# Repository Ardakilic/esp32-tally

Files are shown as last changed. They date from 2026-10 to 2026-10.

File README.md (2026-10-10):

# ESP32 Tally Counter

A pocket tally counter: two buttons, a 0.91" OLED, an ESP32-C3 Super Mini and a
1000 mAh LiPo in a 58 × 58 × 22 mm 3D-printed case. Right button counts up, left
counts down, hold both for a second to reset. The count survives power-off, the
device deep-sleeps after 60 s and wakes on any button, and a slide switch cuts
power completely. Two firmwares share the same hardware: a **plain** one with no
radio, and an **ESPHome** one that exposes the count to Home Assistant. Everything
— the case STLs, the README images, both firmware binaries — is generated from
source through Docker + `make`; nothing is installed on the host.

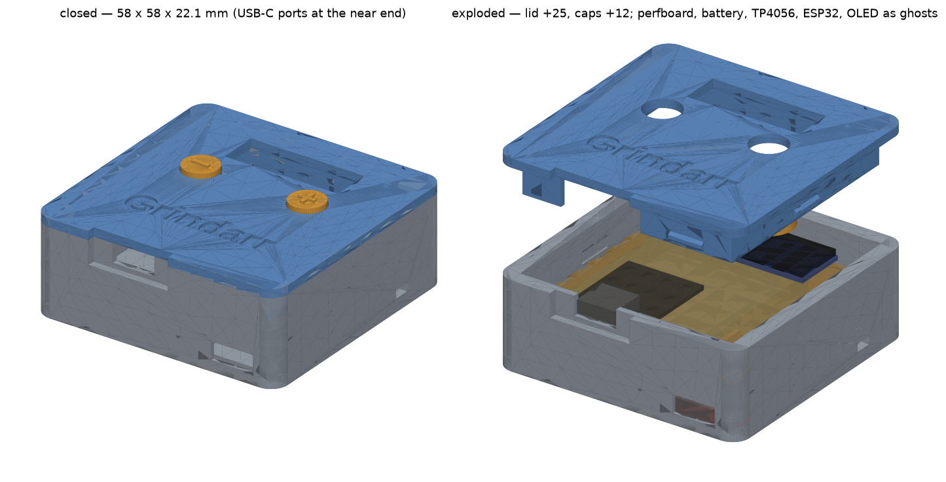
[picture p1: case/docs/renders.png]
Tally counter case — closed and exploded

*Closed (58.0 × 57.6 × 22.1 mm, both USB-C ports at the near end, "Grindarr"
engraved in the lid) and exploded, with perfboard, battery, TP4056, ESP32 and OLED
as ghosts.*

**Interactive preview:** [ardakilic.github.io/esp32-tally](https://ardakilic.github.io/esp32-tally/)
— or open [`case/preview.html`](case/preview.html) locally (self-contained, works offline).

## Features

- **UP** (right, "+") and **DOWN** (left, "−") buttons, range 0…99999, DOWN stops
  at 0; a click counts on **release**, debounced 20 ms.
- Hold **both ≥ 1 s → reset to 0**; the two releases that follow do not count.
- Count **saved to flash on every click** (NVS on the plain build, ESPHome `globals`
  with `restore_value` on the other): a power cut never loses a count. NVS is
  log-structured, so that is tens of millions of clicks before wear matters.
- **60 s idle → OLED off + deep sleep**; either button wakes it (that press is not
  counted). Slide switch = hard power off.
- **Charging over USB-C** through a TP4056 module with cell protection; the ESP32's
  own USB-C is for flashing only and sits behind the lid (see [Power notes](#power-notes)).
- ESPHome variant adds Home Assistant entities: number **Tally Count** (settable),
  button **Reset Tally**, switch **Keep Awake** (blocks the idle sleep so OTA can run).
- Case: snap-fit lid (four detents, bite tunable with [`--snap-bite`](#fit-tuning),
  `0` = plain friction fit), no screws, no supports, 4 parts, 26 cm³ of plastic; the
  lid is engraved "Grindarr" by default — any text or none ([Engraving](#engraving)).

## Bill of materials

| Part | Notes |
|---|---|
| ESP32-C3 Super Mini | the 18 × 22.5 mm board with two 8-pin rows; on male pin headers |
| 0.91" SSD1306 OLED, 128 × 32, I2C | 4-pin header (GND VCC SCL SDA on most — verify yours), address 0x3C |
| 2 × 6 × 6 mm tact switches | any height 4.3–6 mm; default 5.0, see [`--tact-height`](#fit-tuning) |
| TP4056 USB-C charger module | the common 17 × 28 mm board **with** DW01 protection (the variant with OUT+/OUT− pads); 1 A default |
| SS12D00 slide switch | 3-pin, 1P2T, 8.8 × 3.9 × 3.5 mm body, 2 mm travel |
| 1S LiPo pouch, 503450 | 34 × 50 × 5 mm, 1000 mAh, with PCM and JST-PH lead; other sizes via [`--battery`](#fit-tuning) (T ≤ 7 mm) |
| [Özdisan 5 × 5 cm perfboard](https://www.ozdisan.com/p/prototipleme-devreleri-621/ozd-arduino-delkl-pertnaks-5x5-643014) | single-sided, 50 × 50 mm, **18 × 19 holes** at 2.54 mm, used **whole** — no cutting |
| Male pin headers | 2 × 8 for the Super Mini |
| Hook-up wire | thin silicone wire for the dozen connections below |
| 4 printed parts | base, lid, cap "+", cap "−" ([Case](#case)) |
| Hot glue | one dab to hold the slide switch — never on the cell or the perfboard |
| Kapton tape (or 0.3–0.5 mm PET / fish paper) + double-sided foam tape | insulate the perfboard's solder side; fix cell and TP4056 to the floor ([Assembly](#assembly)) |
| Optional: 3 mm foam pad | under the OLED's free end so it can't rock on its header |

## Wiring

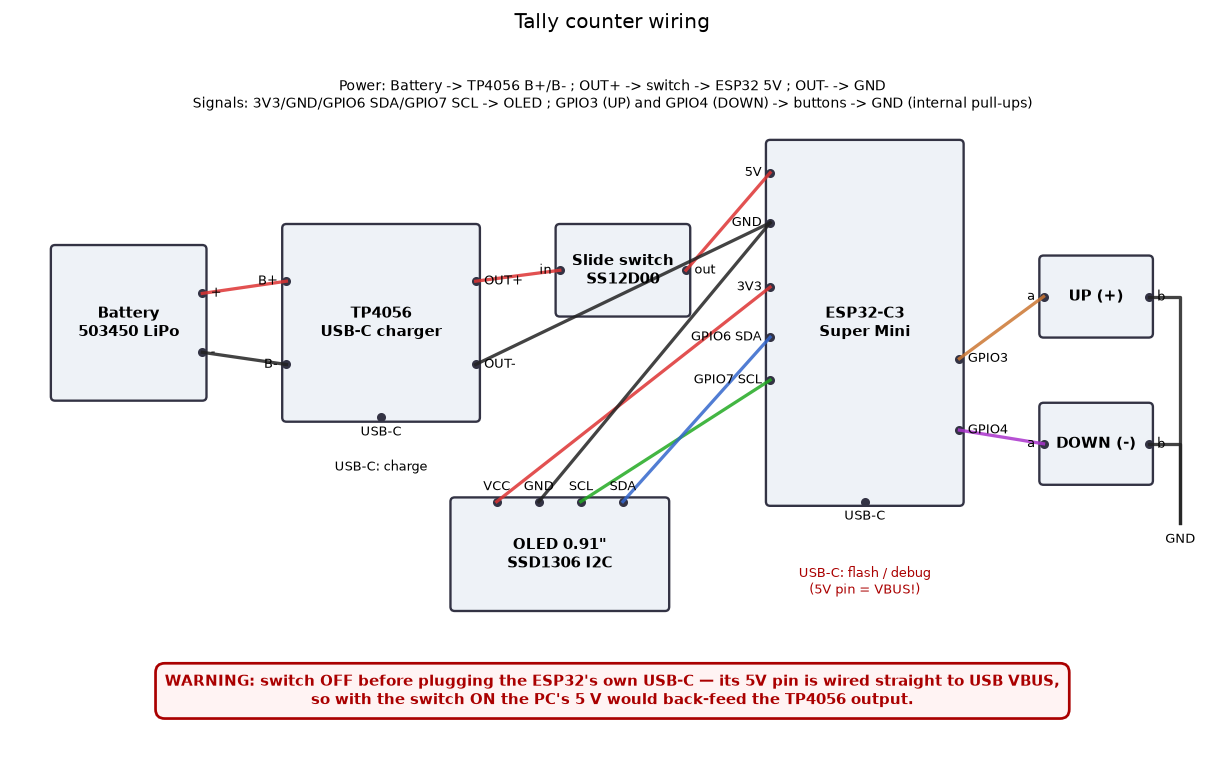
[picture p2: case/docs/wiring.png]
Wiring block schematic


| From | To | Notes |
|---|---|---|
| Battery + / − | TP4056 `B+` / `B−` | solder the JST-PH lead directly to the pads |
| TP4056 `OUT+` | slide switch common | the switched node is on the **high** side |
| slide switch throw (one of the two) | ESP32 `5V` | `5V` = USB VBUS net, see Power notes |
| TP4056 `OUT−` | ESP32 `GND` | OUT− is the protection-switched ground — star all grounds here |
| ESP32 `3V3` / `GND` | OLED `VCC` / `GND` | |
| ESP32 `GPIO6` | OLED `SDA` | I2C 0x3C |
| ESP32 `GPIO7` | OLED `SCL` | |
| UP button, pin 1 / pin 2 | ESP32 `GPIO3` / `GND` | internal pull-up, active low |
| DOWN button, pin 1 / pin 2 | ESP32 `GPIO4` / `GND` | internal pull-up, active low |

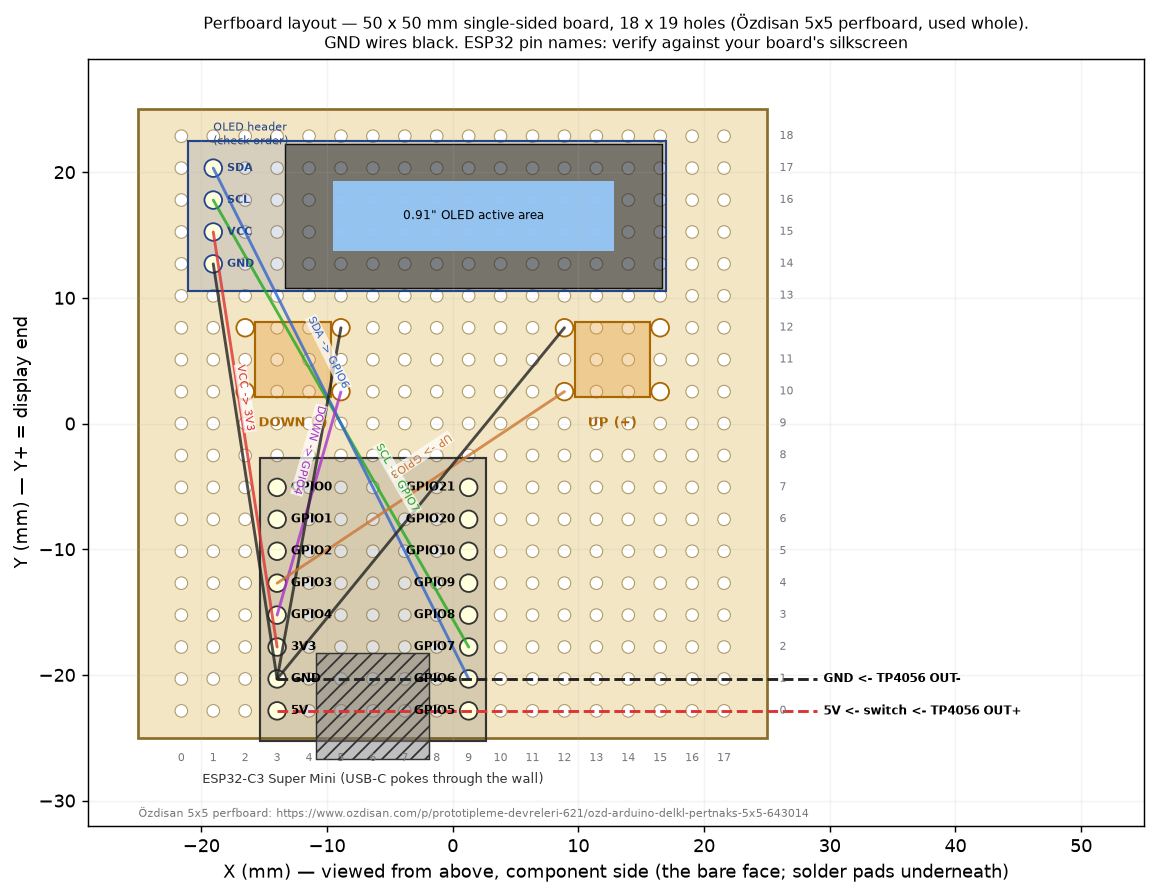
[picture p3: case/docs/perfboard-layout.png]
Perfboard layout


The perfboard is an [Özdisan 5 × 5 cm single-sided board](https://www.ozdisan.com/p/prototipleme-devreleri-621/ozd-arduino-delkl-pertnaks-5x5-643014)
used **whole**: 50 × 50 mm, 18 × 19 holes at 2.54 mm, no cutting. It drops onto the
ledge inside the case with the 19-hole direction along the length (Y, towards the
display end) and the 18-hole direction across (X). The hole grid is centred on the
board — outer row centres 2.14 mm from the Y edges, outer column centres 3.41 mm
from the X edges. Single-sided means the square solder pads are on one face only:
components sit on the bare face, pads underneath. The drawing above is the
**component-side view**, so hole positions appear mirrored once you flip the board
to solder. Column 0 / row 0 is the bottom-left corner when the display end is up.
The Super Mini's two pin rows go into **columns 3 and 9, rows 0…7**, USB-C at the
bottom edge — column 3 carries 5V, GND, 3V3, GPIO4, GPIO3, GPIO2, GPIO1, GPIO0
from the USB end up and column 9 carries GPIO5, GPIO6, GPIO7, GPIO8, GPIO9,
GPIO10, GPIO20, GPIO21 (verified against the mischianti photo pinout and on a
real board, 2026-10-10); because row 0 sits only 2.14 mm from the board edge the receptacle
face ends up just 1.72 mm past the perfboard, so the case wall is relieved from
the outside to a 1.4 mm thin wall there and the port sits 0.2 mm behind it.
The two tact switches are centred at **X ±12.7 mm on row 11** — their four legs land
in columns 2 & 5 (DOWN) and 12 & 15 (UP), rows 10 & 12. The OLED's 4-pin header
goes into **column 1, rows 14…17**, with the module extending to the right across
the top of the board. Pin names in the drawing match the real board — still
**verify against your board** before soldering, Super Mini pinout images disagree
on mirroring; OLED header order varies (GND VCC SCL SDA on most modules).

> **Rework note.** If you built the board from a drawing dated before 2026-10-10,
> the two ESP32 columns were mirrored: move every wire that lands on the module
> to the other column at the same row (5V, GND, 3V3, SDA, SCL, UP, DOWN) — the
> firmware is unchanged.

### Power notes

Verified from the Super Mini schematic (links in
[Verified part geometry](#verified-part-geometry)):

- **The `5V` header pin is the USB VBUS net** — it sits *before* the BAT60J Schottky
  diode and the ME6211 3.3 V LDO. **Flip the slide switch OFF (or unplug the
  battery) before plugging a cable into the ESP32's own USB-C**, otherwise the PC's
  5 V back-feeds the TP4056 output and the battery. This is why the case hides the
  ESP32 port: you open the lid to flash.
- Battery path: V<sub>bat</sub> → BAT60J (≈0.2–0.3 V drop) → ME6211 → 3V3. Regulation
  holds down to ≈3.6–3.7 V; below ≈3.4 V the 3V3 rail sags — the plain build keeps
  running, the Wi-Fi build may brown out. The TP4056's DW01 cuts the cell at 2.4 V
  regardless, so nothing is damaged, the display just gets flaky near empty.
- The Super Mini's **red power LED** draws ≈1–3 mA even in deep sleep when fed
  through `5V`. Flip the switch when storing the counter, or desolder that LED
  for µA-level sleep.
- **Charge current** is the TP4056 default **1 A** (R<sub>PROG</sub> 1.2 kΩ): fine
  for cells ≥ 1000 mAh. For smaller cells swap R<sub>PROG</sub> (2 kΩ ≈ 580 mA).
- **Charge with the switch OFF** so the TP4056's full-charge indication isn't
  confused by the load.
- **Charging/USB test with the switch ON** back-feeds the cell through `OUT+` =
  `B+` with no current control; macOS may disable the port ("USB Accessories
  Disabled"). **Switch OFF first, always.**
- `OUT−` is the protection-switched node (DW01 switches the low side): star the
  grounds at `OUT−`, never at `B−`.

## Firmware

Both firmwares implement the same behaviour and pinout; pick one. Build outputs
are gitignored — `make` regenerates them from pinned Docker images.

### Plain (no network)

[`firmware/plain/`](firmware/plain/) — PlatformIO + Arduino core 3.3.12
(pioarduino platform 55.03.312-1), board `nologo_esp32c3_super_mini`,
`flash_mode = dio`, one library: U8g2 2.36.18.

| File | Role |
|---|---|
| [`platformio.ini`](firmware/plain/platformio.ini) | platform / board / U8g2 pins |
| [`src/tally_logic.h`](firmware/plain/src/tally_logic.h) | the button/count state machine — pure C++, no Arduino |
| [`src/main.cpp`](firmware/plain/src/main.cpp) | pins, OLED, NVS (`Preferences`, written on every click), deep sleep, boot blink + serial banner |
| [`test/tally_logic_test.cpp`](firmware/plain/test/tally_logic_test.cpp) | assert-based self-test of the state machine, runs on the host in `gcc:14` |
| [`Dockerfile`](firmware/plain/Dockerfile) | `python:3.12-slim` + platformio 6.2.0 + git, `PLATFORMIO_CORE_DIR=/pio` |

```bash
make plain-test   # host self-test: prints OK
make plain        # -> firmware/plain/build/tally-plain.factory.bin
```

Result: RAM 4.6 % (15.2 KB), Flash 25.2 % (330 KB), merged image 403 KiB. The
`.factory.bin` is the complete flash image (bootloader @0x0, partitions @0x8000,
boot_app0 @0xe000, app @0x10000) — flash it at offset 0. No OTA: reflashing means
opening the lid.

Liveness check: the Super Mini's **blue LED** (GPIO8) blinks ≈0.3 s on every boot
and wake, so a blink with a dark OLED means the MCU runs and the display (or its
wiring) is the problem. The USB serial port (115200) prints
`boot reset=<esp_reset_reason> wake=<esp_sleep_wakeup_cause>` and the restored
count at boot, then `count=N` per click. A button stuck low (solder bridge, jammed
cap) cannot hold the chip awake: `setup()` seeds the button state instead of
waiting for a release (so the wake press still doesn't count), and a pin that is
low at sleep time is left out of the wake mask.

### ESPHome (Home Assistant)

[`firmware/esphome/tally.yaml`](firmware/esphome/tally.yaml) — ESPHome 2026.9.1,
`esp-idf` framework, board `nologo_esp32c3_super_mini`. Substitution
`idle_sleep: 60s`. Entities in HA: number **Tally Count** (0…99999, box mode,
settable), button **Reset Tally**, switch **Keep Awake**.

1. Secrets: `cp firmware/esphome/secrets.yaml.example firmware/esphome/secrets.yaml`
   and fill in `wifi_ssid`, `wifi_password`, `api_key` (`openssl rand -base64 32`;
   used for both the HA API and OTA) and `ap_password` (fallback hotspot, ≥ 8 chars).
   `secrets.yaml` is gitignored; `make esphome` refuses to run without it.
2. Build (the container needs internet the first time: the Roboto font comes from
   Google Fonts at compile time, the IDF toolchain lands in the cache volume):

```bash
make esphome-config   # validate tally.yaml
make esphome          # -> firmware/esphome/.esphome/build/tally/build/firmware.factory.bin (983 KB)
                      #    and firmware.ota.bin next to it
make esphome-ota      # compile + OTA to DEVICE (default tally.local) after the first USB flash
```

Result: Flash 51 %, RAM 33 %. The device **still sleeps after 60 s** with Wi-Fi: HA
shows it unavailable in between, it reconnects on every wake and pushes the count.
Before an OTA, press a button to wake it and turn on **Keep Awake** within 60 s;
turning it off re-arms the idle timer.

### Flashing

Docker Desktop on macOS cannot pass USB through, so flash from the browser:

1. **Slide switch OFF** (or battery disconnected) — see [Power notes](#power-notes).
2. Open <https://web.esphome.io> in Chrome or Edge → **Connect** → pick the Super
   Mini's serial port → **Install** → choose the `.factory.bin`
   (`firmware/plain/build/tally-plain.factory.bin` or
   `firmware/esphome/.esphome/build/tally/build/firmware.factory.bin`).
3. If no port shows up, hold **BOOT** (GPIO9) while plugging the cable in, then retry.

Both images are full factory images, so switching between the two firmwares is just
another flash. After the first ESPHome flash, later updates go over the air
(`make esphome-ota`).

## Case

[`case/`](case/) — one Python script ([`generate.py`](case/generate.py), shapely +
trimesh + manifold3d, pinned, `python:3.14-slim`) builds four watertight STLs; the
same constants drive the README images and the geometry self-test.

### Parts

| STL | Size (mm) | Volume | Print orientation |
|---|---|---|---|
| [`case/stl/tally-base.stl`](case/stl/tally-base.stl) | 58.0 × 57.6 × 20.1 | 17.2 cm³ | upright, as exported |
| [`case/stl/tally-lid.stl`](case/stl/tally-lid.stl) | 58.0 × 57.6 × 9.5 | 7.4 cm³ | as exported (top face down) |
| [`case/stl/tally-cap-plus.stl`](case/stl/tally-cap-plus.stl) | 11 × 11 × 6 | 0.4 cm³ | on its flange, as exported |
| [`case/stl/tally-cap-minus.stl`](case/stl/tally-cap-minus.stl) | 11 × 11 × 6 | 0.4 cm³ | on its flange, as exported |

Closed: **58.0 × 57.6 × 22.1 mm** (frame opening 50.6 × 50.6, cavity 54.0 × 53.6).
Shell 2.0 mm walls / floor / lid plate, 1.2 mm lid skirt, 4 mm outer corner radius.
Features: snap-fit lid whose skirt slides *inside* the frame (0.28 mm clearance
per side) and clamps the perfboard onto an internal ledge — four 8 mm snap detents
on the skirt's outer face (X− and X+ walls at Y = 0, Y+ wall at X = 0, Y− wall
right of the USB notch at X = +14.2) click into closed 0.5 mm grooves in the
frame's inner face; the crest bites 0.4 mm past the frame, both ramps are 45° so
the lid still pries off, and `--snap-bite 0` gives the plain friction fit; 27 × 9 mm OLED
window; two Ø8.4 mm cap holes; "Grindarr" engraved 0.6 mm into the lid top
([Engraving](#engraving)); an open-top slot in the bottom wall for the ESP32's
USB-C, closed by a notch in the lid skirt (left, flash/debug) — the wall's outer
face is relieved there to a 1.4 mm thin wall, 19 mm wide, and the lid plate is
notched over it so a plug reaches the port; a USB-C window at floor level for the
TP4056 (right, charge); slide-switch slot on the right wall; 10 × 1.5 mm pry notch
at the display end.

### Printing

- 0.2 mm layers, 0.4 mm nozzle. **PETG preferred**: the lid skirt flexes ≈0.7 mm
  riding over the snap bumps. For PLA print a shallower bite,
  `make case GEN_ARGS="--snap-bite 0.3"` (or `--snap-bite 0` for the plain friction
  fit).
- **No supports** in the exported orientations — the overhangs are the ledge's
  underside inside the base, 1.5 mm (ends) to 1.7 mm (sides) wide, and the four
  snap-groove ceilings (0.5 mm deep); both print fine at 0.2 mm layers. The lid's
  snap bumps are 45° ramps and print face-down as before.
- The **thin 1.4 mm wall around the ESP32 port is intentional** (plug relief in the
  bottom wall's outer face, 19 mm wide, from 2 mm above the perfboard up to the
  rim) — don't thicken it in the slicer.
- Base upright; lid as exported (top face on the bed, so the window edge, the
  engraving and the outer face are clean); caps on their flanges.

### Assembly

1. **TP4056**: USB-C first into the lower opening at the bottom end, the PCB end
   sinks 1 mm into its wall pocket; it lies against the right wall, the stop block
   sits behind it.
2. **Battery** into the left bay (lead towards the TP4056; the rib between them
   keeps the pouch off the charger).
3. **Slide switch**: drop it between its two ribs from the inside, handle through
   the slot in the right wall; a dab of hot glue holds it.
4. Solder and route the wires (table above); keep them below the ledge.
5. **Insulate the solder side**: clip every pin tail under the perfboard to
   ≤ 1 mm, then cover the **whole** solder side with Kapton/polyimide tape (two
   layers over the header stubs) or a 0.3–0.5 mm PET / fish-paper sheet cut to
   50 × 50. The ESP32 and OLED header stubs sit directly over the battery bay with
   ≈2 mm of air; a LiPo pouch is 40 µm aluminium foil under 25 µm of nylon, so two
   stubs pressed into it are shorted together (SDA and SCL are 2.54 mm apart), and
   the TP4056's USB shell and `B−`/`OUT−` pads are ground.
6. **Fix the cell and the TP4056 to the case floor** with double-sided foam tape —
   never hot glue against the pouch or the perfboard underside. Hot glue
   (175–200 °C) plus pressure on a pouch is a safety risk, and glue that shrinks or
   is peeled off later cracks single-sided solder joints (the OLED's four first).
7. **Perfboard** onto the ledge, pads down, ESP32 USB-C end towards the bottom
   edge, so the receptacle sits in its wall slot.
8. **Caps** into the lid from below — "+" on the right, "−" on the left (as held,
   display up).
9. **Lid** on: the skirt notch goes over the ESP32 end; press down until it clicks
   on all four sides.

Open it by lifting with a coin in the pry notch at the display end — the detents'
release ramps are 45°, so the lid pries off. Optionally stick a 3 mm foam pad under
the OLED's free end before closing.

### Field notes

First build, 2026-10-10: with the TP4056 and cell hot-glued under the board the
OLED stayed dark until the glue came off — contact through the header stubs and
joint stress, not EMI; hence steps 5–6. Dark-display triage, in order: press
**RST**; the serial port appears (`ls /dev/cu.usbmodem*`) and vanishes after 60 s
(deep sleep); [web.esphome.io](https://web.esphome.io) → **Logs** shows `count=N`
per click; the blue GPIO8 blink on boot = MCU alive; then meter the OLED header
(VCC 3.3 V, SDA/SCL idle at 3.3 V) and reflow. A deep-sleeping ESP32-C3 does
**not** wake when USB is plugged in — only a button or RST does — and with the
slide switch ON a USB plug back-feeds the cell ([Power notes](#power-notes)).

### Fit tuning

Printers and kits vary; the four fit parameters (and the lid engraving) are
command-line flags shared by the generator, the image renderer and the verifier:

| Flag | Default | Controls |
|---|---|---|
| `--clear-friction` | 0.28 mm | lid skirt clearance to the frame per side (filtarr's calibrated value); tune in ±0.04 steps |
| `--snap-bite` | 0.4 mm | how far the four lid snap detents bite past the frame's inner face (PETG); PLA ≈ 0.3; `0` = no detents, the plain friction fit (STLs byte-identical to the pre-snap case) |
| `--tact-height` | 5.0 mm | tact switch height, PCB top to plunger top — 4.3 / 5 / 6 are fine, ≤ 6.0 with the default 7.5 mm lid clearance |
| `--battery` | 34x52x6 | battery pouch envelope W×L×T incl. tabs and swelling; T ≤ 7 |
| `--engraving TEXT` | `Grindarr` | text engraved into the lid top ([Engraving](#engraving)); shortcut `make case ENGRAVING="My Text"` |
| `--omit-engraving` | off | plain lid top, no text; shortcut `make case OMIT_ENGRAVING=1` |

```bash
make case GEN_ARGS="--clear-friction 0.32"                  # lid too tight
make case GEN_ARGS="--snap-bite 0.3"                        # PLA lid; 0 = no detents
make case GEN_ARGS="--tact-height 4.3"                      # shorter switches
make case GEN_ARGS="--battery 30x40x5"                      # smaller cell
make case ENGRAVING="My Text"                               # other lid text
make case OMIT_ENGRAVING=1 GEN_ARGS="--tact-height 4.3"     # plain lid; combinable
make case-verify GEN_ARGS="--clear-friction 0.32 --tact-height 4.3"   # check before printing
```

Every other dimension (walls, PCB_Z 9, LID_CLEAR 7.5, window 27 × 9, switch
position SW_Y 14, snap bump SNAP_LEN 8 / SNAP_CREST 0.8, …) is a named constant
with a why-comment at the top of
[`case/generate.py`](case/generate.py).

### Engraving

The lid top carries **"Grindarr"** by default: Liberation Sans Bold, 6 mm cap
height, recessed 0.6 mm (3 layers), centred at (0, −13) in the free band between
the button caps and the USB-port edge, reading upright with the display at the
top. The lid prints top-face-down, so the recess sits on the bed and comes out
crisp. `--engraving TEXT` / `--omit-engraving` (or the `ENGRAVING=` /
`OMIT_ENGRAVING=1` make shortcuts, which append to `GEN_ARGS`) go to
`generate.py`, `verify.py` and `render_docs.py` alike. Longer text auto-shrinks
below 6 mm to stay inside the band; empty text or a glyph the font has no outline
for is rejected (`p.error`). The generator's summary line — repeated in the
preview's Dimensions panel — reads `Engraving: "Grindarr" (6 mm, 0.6 deep)` or
`Engraving: omitted`. The output is `stl/tally-lid.stl` either way; the committed
lid, renders and preview carry "Grindarr". The font comes from `fonts-liberation`
in the case Docker image.

## Interactive preview

Online at **[ardakilic.github.io/esp32-tally](https://ardakilic.github.io/esp32-tally/)**
(the [Pages workflow](.github/workflows/pages.yml) republishes the whole checkout on
every push to `main`; enable Pages once with Source = GitHub Actions), or locally —
[`case/preview.html`](case/preview.html) is one self-contained file (three.js and the
four STLs embedded, no internet needed), open it in any browser. Lift the lid and caps
with the **Explode** slider, toggle each part, switch on **X-ray lid** or the ghost
electronics (perfboard, battery, TP4056, ESP32, OLED, slide switch), and download
the exact STLs from the **Print these four** list; the Dimensions panel repeats the
tolerance, snap, shell and engraving summary `generate.py` prints, so a tuned build shows
its `GEN_ARGS` (the lid's engraving is in the embedded STL). The landing page ([`index.html`](index.html)) links the preview, the
STLs, the README images and both firmware folders.

## Regenerating everything

```bash
make                  # case + plain + esphome
```

| Target | Does | Output |
|---|---|---|
| `make case` | build image, `generate.py`, `tools/render_docs.py`; `ENGRAVING="…"` / `OMIT_ENGRAVING=1` set the lid text | `case/stl/*.stl`, `case/preview.html`, `index.html`, `case/docs/*.png` |
| `make case-verify` | 105 geometry checks on in-memory builds (70 with `--snap-bite 0`, 101 with `--omit-engraving`), exit 1 on failure | PASS/FAIL table |
| `make vendor` | fetch the latest three.js module build (stdlib-only, bare `python:3.14-slim`) | `case/vendor/three.{module,core}.min.js`, `THREE_VERSION` |
| `make plain` | build image, `pio run`, copy the factory image | `firmware/plain/build/tally-plain.factory.bin` |
| `make plain-test` | state-machine self-test in `gcc:14` | `OK` |
| `make esphome` | `esphome compile` (needs `secrets.yaml`) | `firmware/esphome/.esphome/build/tally/build/firmware.{factory,ota}.bin` |
| `make esphome-config` | `esphome config` | validated YAML |
| `make esphome-ota` | `esphome run --device $(DEVICE)` | flashed device |
| `make image-case` / `make image-plain` | (re)build the two Docker images | — |
| `make clean` | removes `case/stl case/docs case/preview.html index.html firmware/plain/.pio firmware/plain/build firmware/esphome/.esphome` | — |

Pinned images: `python:3.14-slim` + [`case/requirements.txt`](case/requirements.txt)
(the exact wheels the committed STLs were triangulated with) + Debian's
`fonts-liberation` for the lid engraving, `python:3.12-slim` +
platformio 6.2.0, `ghcr.io/esphome/esphome:2026.9.1`, `gcc:14`. Caches live in two
named Docker volumes, never on the host: **`esp32-tally-pio`** (PlatformIO core —
pioarduino platform, Xtensa/RISC-V toolchain, Arduino framework, U8g2) and
**`esp32-tally-esphome-cache`** (ESPHome's PlatformIO/IDF cache). First builds
download a few hundred MB into them; rebuilds take seconds. `make clean` leaves
the volumes alone (`docker volume rm esp32-tally-pio esp32-tally-esphome-cache`
if you want them gone).

`case/stl/`, `case/docs/`, `case/preview.html`, `index.html` and `case/vendor/` are
**committed and never hand-edited**: change `generate.py` (or
`case/preview_template.html`), run `make case` + `make case-verify` (or
`make case ENGRAVING="…"` for another lid text), commit the regenerated files
together with the change; `make vendor` only when you want a newer three.js.
`make case-verify` ([`case/tools/verify.py`](case/tools/verify.py)) rebuilds every
part in memory and checks: watertightness; bounding boxes; skirt = opening − 2 ×
clearance; rays through the OLED window, both cap holes, both USB-C openings and
the switch slot; the 1.4 mm wall and port recess at the ESP32 USB-C; that the
battery, TP4056, ESP32, OLED and switch ghosts do not intersect the shell; the
cap-to-hole play; the engraving's depth and footprint (or a plain top with
`--omit-engraving`); and, per snap site, the crest protrusion, groove depth,
seated Z/along-the-wall margins, remaining frame wall, clearance to the USB
relief and skirt notch, plus that `--snap-bite 0` reproduces the no-snap lid and
base exactly. Pass it the same `GEN_ARGS` as `make case`.

## Verified part geometry

Dimensions the case is built around (all in `generate.py` with their sources):

- **ESP32-C3 Super Mini** — PCB 18 × 22.5 mm, two 8-pin rows 15.24 mm apart
  (6 pitches), first pin centre 2.36 mm from the USB edge, USB-C shell 9 × 3.2 mm
  overhanging the PCB by 1.5 mm, module on 2.54 mm header spacers + 1.0 mm PCB;
  `5V` pin = VBUS before the BAT60J diode and ME6211 LDO —
  [schematic (mischianti.org)](https://mischianti.org/wp-content/uploads/2025/07/esp32-c3-supermini-schematics.pdf).
- **ME6211** LDO (3.3 V variant on the board) — low dropout, hence the ≈3.6–3.7 V
  regulation floor quoted above —
  [family datasheet (LCSC)](https://wmsc.lcsc.com/wmsc/upload/file/pdf/v2/lcsc/2201121200_MICRONE-Nanjing-Micro-One-Elec-ME6211C25M5G_C2835813.pdf).
- **6 × 6 mm tact switch** — Omron B3F family: body 6 × 6, plunger Ø3.5, heights
  4.3 / 5.0 / 6.0 / 7.0 mm, legs 6.5 × 4.5 mm apart → 3 × 2 perfboard pitches
  (columns 2 & 5 / 12 & 15, rows 10 & 12) —
  [B3F datasheet](https://omronfs.omron.com/en_US/ecb/products/pdf/en-b3f.pdf).
- **SS12D00 slide switch** — body 8.8 × 3.9 × 3.5 mm, handle 1.5 mm, travel 2.0 mm
  (slot 4.0 × 2.0 mm incl. 0.5 mm play) —
  [datasheet](https://www.vimex.com/switches/techdocs/SS12D00-tech.pdf).
- **0.91" 128 × 32 OLED** — module PCB 38 × 12 mm, glass 30 × 11.5 mm, active area
  22.4 × 5.6 mm, header pin centres 2.0 mm from the short edge, 6.9 mm tall at the
  IC seal cover — [panel datasheet](https://www.icbanq.com/icdownload/V2_DATA/ICBShop/Board/HP12832-01-TSWG14P091-A-VER1.0.pdf).
- **TP4056 USB-C module** — PCB 17 × 28 × 1.0 mm, USB-C shell 9 × 3.2 mm overhanging
  1.0 mm, R<sub>PROG</sub> 1.2 kΩ → 1 A, DW01 protection switching the low side —
  [module manual](https://shillehtek.com/blogs/shillehtek-product-manuals/tp4056-1a-lipo-battery-charging-board-type-c-with-current-protection-manual).
- **503450 LiPo** — 34 × 50 × 5 mm nominal, modelled as 34 × 52 × 6 (PCM tab +
  1 mm swelling) with 0.5 mm air to every wall.
- **Perfboard** — Özdisan 5 × 5 cm single-sided board, used whole: 50 × 50 mm,
  1.6 mm FR4, 18 × 19 holes at 2.54 mm centred on the board (outer row centres
  2.14 mm from the Y edges, outer column centres 3.41 mm from the X edges), square
  pads on one face —
  [product page (Özdisan)](https://www.ozdisan.com/p/prototipleme-devreleri-621/ozd-arduino-delkl-pertnaks-5x5-643014).

## Not yet verified on hardware

One unit has been printed, assembled on the Özdisan board and flashed with the
plain firmware (2026-10-10, see [Field notes](#field-notes)); the ESPHome build
has not run on hardware yet. The rest is from datasheets, the schematic, the
geometry self-test and a host-side test of the state machine. Still open, in the
order they'd bite:

- **Deep-sleep wake on both buttons** (GPIO3 | GPIO4 mask via
  `esp_deep_sleep_enable_gpio_wakeup`) — compiles on both builds, untested on
  silicon; so is the plain build's GPIO8 blue boot blink.
- The ESPHome **`millis() > 1500` wake-press guard** (the press that woke the chip
  is already ON at boot; its release must not count) — margin chosen by reasoning,
  not measured boot time.
- **Friction fit 0.28 mm** is filtarr's calibrated value on a different, larger
  part; expect to tune `--clear-friction`.
- **Snap detents** — 0.4 mm bite, 8 mm bumps, 45° ramps: click force, pry-off
  force and skirt durability (≈0.7 mm flex per close) are unprinted, in PETG and
  PLA alike; the PLA value `--snap-bite 0.3` is reasoning, not measurement.
  `--snap-bite 0` falls back to the friction-only lid.
- **OLED window offset** `OLED_AA_DX` 3.7 mm (active area vs PCB centre) — measure
  your module; it differs between 0.91" boards.
- **OLED header order** — GND VCC SCL SDA assumed in the drawings.
- **TP4056 variant size** — 17 × 28 mm boards are the norm, some USB-C variants
  are 17 × 26 or have the receptacle further in; the wall pocket is 1 mm deep.
- **Thin 1.4 mm wall at the ESP32 USB-C** — the port face ends 0.2 mm behind it;
  whether every cable's overmold seats, and whether the wall prints cleanly at
  that thickness, is unprinted.
- **Engraving legibility** — 6 mm Liberation Sans Bold, 0.6 mm deep, printed
  face-down on the bed; counters of the small letters are untested with a 0.4 mm
  nozzle.

Found something? Open an issue with the measurement.

## License

Dual-licensed:

- **Code** (firmware, generator, tooling): [MIT](LICENSE)
- **Models & images** (STLs, renders): [CC BY 4.0](LICENSE-MODELS) — use, share,
  sell and remix freely, but credit this project with a link back when you
  redistribute the models.

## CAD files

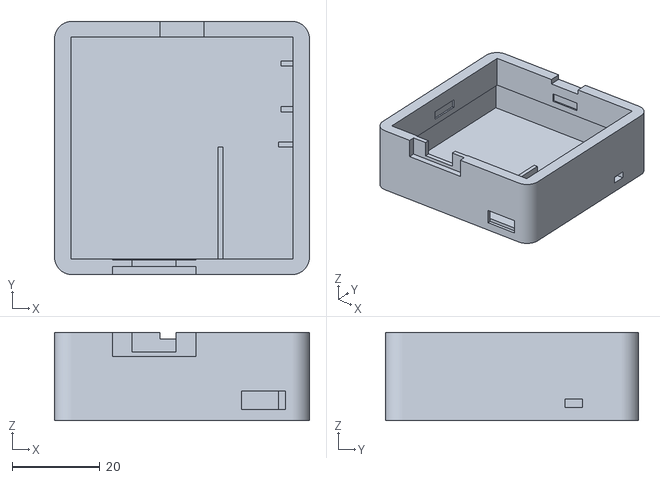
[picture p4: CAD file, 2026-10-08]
case/stl/tally-base.stl
58.0 x 57.6 x 20.1

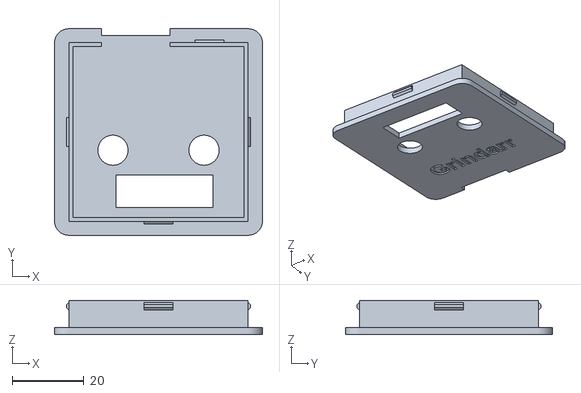
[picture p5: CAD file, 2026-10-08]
case/stl/tally-lid.stl
58.0 x 57.6 x 9.50

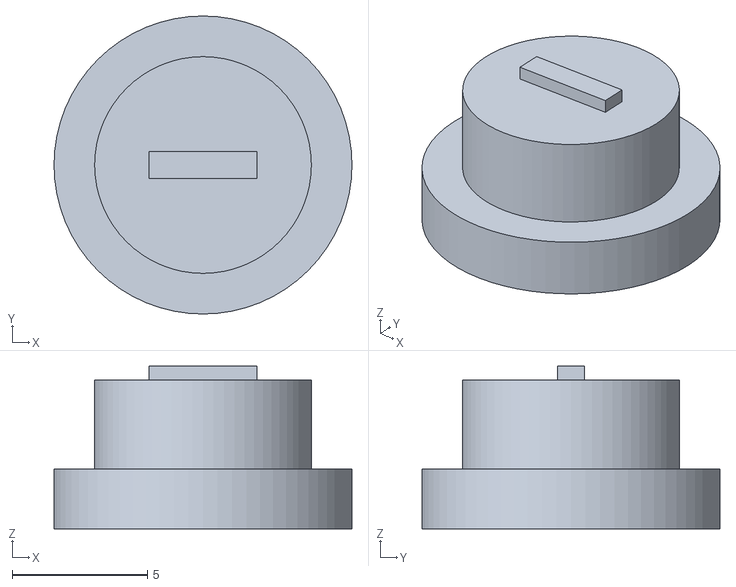
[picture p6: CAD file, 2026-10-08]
case/stl/tally-cap-minus.stl
11.0 x 11.0 x 6.00

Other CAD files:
case/stl/tally-cap-plus.stl

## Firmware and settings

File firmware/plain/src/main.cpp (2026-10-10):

#include <Arduino.h>
#include <Preferences.h>
#include <U8g2lib.h>
#include <esp_sleep.h>
#include "tally_logic.h"

constexpr int BTN_UP = 3, BTN_DOWN = 4;
// Super Mini blue LED: active-LOW with a 10k pull-up, and a strapping pin (must be high at reset).
// Lit only while setup() runs, so a blink on every boot/wake proves the MCU is alive with a dark OLED.
constexpr int LED_PIN = 8;
constexpr uint32_t IDLE_SLEEP_MS = 60000;

U8G2_SSD1306_128X32_UNIVISION_F_HW_I2C u8g2(U8G2_R0, U8X8_PIN_NONE, /*clock=*/7, /*data=*/6);
Preferences prefs;
Tally tally;

static void draw() {
  char buf[8];
  snprintf(buf, sizeof buf, "%ld", (long)tally.count);
  u8g2.clearBuffer();
  u8g2.drawStr((128 - u8g2.getStrWidth(buf)) / 2, 16, buf);
  u8g2.sendBuffer();
}

static void sleepNow() {
  u8g2.setPowerSave(1);
  uint64_t mask = (digitalRead(BTN_UP) ? BIT(BTN_UP) : 0) | (digitalRead(BTN_DOWN) ? BIT(BTN_DOWN) : 0);
  if (mask) esp_deep_sleep_enable_gpio_wakeup(mask, ESP_GPIO_WAKEUP_GPIO_LOW);  // a held/stuck pin would re-wake instantly
  esp_deep_sleep_start();
}

void setup() {
  pinMode(LED_PIN, OUTPUT);
  digitalWrite(LED_PIN, LOW);
  Serial.begin(115200);
  Serial.setTxTimeoutMs(0);  // USB CDC with no host attached must never stall the loop
  Serial.printf("boot reset=%d wake=%d\n", (int)esp_reset_reason(), (int)esp_sleep_get_wakeup_cause());
  pinMode(BTN_UP, INPUT_PULLUP);
  pinMode(BTN_DOWN, INPUT_PULLUP);
  prefs.begin("tally");
  tally.count = prefs.getInt("count", 0);
  Serial.printf("count=%ld (restored)\n", (long)tally.count);
  u8g2.begin();
  u8g2.setFont(u8g2_font_logisoso28_tn);
  u8g2.setFontPosCenter();
  draw();
  digitalWrite(LED_PIN, HIGH);
  pinMode(LED_PIN, INPUT);  // the pull-up keeps it off through deep sleep at zero drive
  // Seed instead of waiting for release: a stuck-LOW button must not block boot and drain the cell.
  tally.up.raw = tally.up.stable = !digitalRead(BTN_UP);
  tally.down.raw = tally.down.stable = !digitalRead(BTN_DOWN);
  tally.combo = tally.up.stable || tally.down.stable;  // the wake press's release must not count
  tally.last_activity_ms = millis();
}

void loop() {
  uint32_t now = millis();
  if (tally.update(!digitalRead(BTN_UP), !digitalRead(BTN_DOWN), now)) {
    draw();
    // Write per click: NVS is log-structured, a 4-byte entry per click into the 20 KB default
    // partition is tens of millions of clicks before wear matters, and a power cut never loses one.
    prefs.putInt("count", tally.count);
    Serial.printf("count=%ld\n", (long)tally.count);
  }
  if (now - tally.last_activity_ms >= IDLE_SLEEP_MS) sleepNow();
  delay(5);
}

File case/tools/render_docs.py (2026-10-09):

#!/usr/bin/env python3
"""Render the README images — software renderer via matplotlib, no GPU/browser:

  docs/renders.png           closed case + exploded view with ghost electronics
  docs/perfboard-layout.png  the 50 x 50 (18 x 19 hole) perfboard from above
                             with every component, pin name and wire
  docs/wiring.png            block schematic (power path + signals)

Usage:  python3 tools/render_docs.py [generate.py flags]
"""

import os
import sys

import numpy as np
import matplotlib

matplotlib.use("Agg")
import matplotlib.pyplot as plt
from matplotlib.patches import Circle, FancyBboxPatch, Rectangle
from mpl_toolkits.mplot3d.art3d import Poly3DCollection
import trimesh

HERE = os.path.dirname(os.path.abspath(__file__))
ROOT = os.path.dirname(HERE)
sys.path.insert(0, ROOT)
import generate as g  # noqa: E402  (has a __main__ guard — importing is free)

DOCS = os.path.join(ROOT, "docs")
GRAY, BLUE, CAP = "#9aa2ad", "#5f8cc4", "#e0a040"
GHOSTS = {  # component box -> translucent colour
    "perfboard": (0.75, 0.55, 0.20, 0.45), "battery": (0.35, 0.65, 0.85, 0.45),
    "tp4056": (0.85, 0.35, 0.35, 0.55), "tp4056-usb": (0.4, 0.4, 0.4, 0.7),
    "esp32": (0.2, 0.2, 0.2, 0.55), "esp32-usb": (0.4, 0.4, 0.4, 0.7),
    "oled": (0.2, 0.3, 0.6, 0.55), "oled-glass": (0.1, 0.1, 0.1, 0.7),
    "switch": (0.9, 0.9, 0.9, 0.9),
}


def show(ax, meshes_cols, elev=28, azim=-55):
    """Flat-shaded render with global painter depth sort (RGBA colours ok)."""
    tris, cols = [], []
    light = np.array([0.35, -0.45, 0.82])
    light /= np.linalg.norm(light)
    for mesh, color in meshes_cols:
        v, f = trimesh.remesh.subdivide_to_size(
            mesh.vertices.astype(np.float64), mesh.faces, max_edge=8.0)
        m = trimesh.Trimesh(v, f)
        shade = 0.5 + 0.5 * np.clip(m.face_normals.astype(np.float64) @ light, 0, 1)
        rgba = np.array(matplotlib.colors.to_rgba(color))
        c = np.tile(rgba, (len(m.faces), 1))
        c[:, :3] = np.clip(shade[:, None] * rgba[None, :3], 0, 1)
        tris.append(m.vertices[m.faces])
        cols.append(c)
    tri, col = np.concatenate(tris), np.concatenate(cols)
    e, a = np.radians(elev), np.radians(azim)
    view = np.array([np.cos(e) * np.cos(a), np.cos(e) * np.sin(a), np.sin(e)])
    order = np.argsort(tri.mean(axis=1) @ view)
    ax.add_collection3d(
        Poly3DCollection(tri[order], facecolors=col[order], edgecolors="none"))
    lo, hi = tri.reshape(-1, 3).min(0), tri.reshape(-1, 3).max(0)
    c, r = (lo + hi) / 2, (hi - lo).max() / 2 * 0.9
    ax.set_xlim(c[0] - r, c[0] + r)
    ax.set_ylim(c[1] - r, c[1] + r)
    ax.set_zlim(c[2] - r, c[2] + r)
    ax.set_box_aspect((1, 1, 1))
    ax.set_proj_type("ortho")
    ax.set_axis_off()
    ax.view_init(elev=elev, azim=azim)


def moved(m, dx=0.0, dy=0.0, dz=0.0):
    c = m.copy()
    c.apply_translation([dx, dy, dz])
    return c


def box_mesh(b):
    return g.bbox(*b)


def render_case(out_path):
    base, lid = g.build_base(), g.build_lid()
    caps = [moved(g.build_cap(s), *xy) for s, xy in zip(("minus", "plus"), g.TACT_XY)]
    closed = [(base, GRAY), (lid, BLUE)] + [(c, CAP) for c in caps]
    ghosts = [(box_mesh(b), GHOSTS[n]) for n, b in g.component_boxes().items() if n in GHOSTS]
    exploded = ([(base, GRAY)] + ghosts + [(moved(c, dz=12.0), CAP) for c in caps]
                + [(moved(lid, dz=25.0), BLUE)])
    fig = plt.figure(figsize=(11, 6), dpi=130)
    ax = fig.add_subplot(1, 2, 1, projection="3d")
    show(ax, closed)
    ax.set_title(f"closed — {g.OUT_W:.0f} x {g.OUT_L:.0f} x {g.Z_TOP + g.LID_T:.1f} mm "
                 "(USB-C ports at the near end)", fontsize=10)
    ax = fig.add_subplot(1, 2, 2, projection="3d")
    show(ax, exploded)
    ax.set_title("exploded — lid +25, caps +12; perfboard, battery, TP4056, "
                 "ESP32, OLED as ghosts", fontsize=10)
    fig.patch.set_facecolor("white")
    plt.tight_layout()
    plt.savefig(out_path, bbox_inches="tight")
    plt.close(fig)
    print("saved", out_path)


# ESP32-C3 Super Mini pin names with the USB at Y-, board viewed from above.
# Left = col 3, right = col 9, rows 0..7 (0 = USB end). Verified against the
# mischianti photo pinout and on a real board 2026-10-10 (an earlier version had
# the two columns mirrored). Still worth a glance at the silkscreen.
ESP_LEFT = ["5V", "GND", "3V3", "GPIO4", "GPIO3", "GPIO2", "GPIO1", "GPIO0"]
ESP_RIGHT = ["GPIO5", "GPIO6", "GPIO7", "GPIO8", "GPIO9", "GPIO10", "GPIO20", "GPIO21"]
OLED_PINS = ["GND", "VCC", "SCL", "SDA"]  # rows 14..17, the usual order — check
OLED_ROWS = range(14, 18)
TACT_ROWS = (10, 12)  # tact pins straddle the body on row 11
ESP_PIN = {**{n: (3, r) for r, n in enumerate(ESP_LEFT)},
           **{n: (9, r) for r, n in enumerate(ESP_RIGHT)}}
# wires: (from hole, to hole, label, colour, label position along the wire 0..1)
WIRES = [
    ((1, 15), ESP_PIN["3V3"], "VCC -> 3V3", "#d33", 0.5),
    ((1, 14), ESP_PIN["GND"], "GND", "#222", 0.5),
    ((1, 16), ESP_PIN["GPIO7"], "SCL -> GPIO7", "#2a2", 0.72),
    ((1, 17), ESP_PIN["GPIO6"], "SDA -> GPIO6", "#36c", 0.45),
    ((5, 10), ESP_PIN["GPIO4"], "DOWN -> GPIO4", "#a3c", 0.5),
    ((5, 12), ESP_PIN["GND"], "GND", "#222", 0.5),
    ((12, 10), ESP_PIN["GPIO3"], "UP -> GPIO3", "#c73", 0.5),
    ((12, 12), ESP_PIN["GND"], "GND", "#222", 0.5),
]
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

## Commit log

2026-10-08 ESP32-C3 tally counter: two firmwares, parametric case, three.js preview
    Handheld click counter on an ESP32-C3 Super Mini with a 128x32 SSD1306 OLED,
    two 6x6 tact buttons (+/-, both held = reset), a TP4056 USB-C charger, a 1S
    LiPo bay and a slide power switch. Count is persisted in flash; the device
    deep-sleeps after 60 s idle and wakes on either button. Everything is
    generated inside Docker (make), nothing is installed on the host.
    - firmware/plain: PlatformIO + Arduino core 3.3 (pioarduino), U8g2, NVS,
    deep sleep; header-only state machine with a gcc self-test
    - firmware/esphome: ESP-IDF build exposing a settable number, a reset
    button and a keep-awake switch to Home Assistant
    - case: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
    [tally-base.stl, tally-cap-minus.stl, tally-cap-plus.stl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]
2026-10-08 Özdisan 50x50 perfboard used whole; optional "Grindarr" lid engraving
    The perfboard is now the specific Özdisan 5x5 cm single-sided board
    (50 x 50 mm, 18 x 19 holes at 2.54 mm) used uncut. The hole grid sits
    further from the board edge than the old cut board, so the Super Mini's
    USB-C port would have been recessed 2 mm; the Y- wall is now relieved
    from the outside to a 1.4 mm thin wall there and the lid plate is notched
    over it, leaving the port 0.2 mm behind the face.
    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
    [tally-base.stl, tally-lid.stl]
2026-10-08 Snap-fit lid: four detents on the skirt, closed grooves in the frame
    The lid was a plain friction fit, which nothing holds when the handheld
    is picked up by the lid or turned over. Four 8 mm detents on the skirt's
    outer face now click into closed 0.5 mm grooves in the frame's inner
    face (X sides at Y 0, Y+ at X 0, Y- right of the USB notch). Symmetric
    45 deg ramps so the lid still pries off at the existing notch.
    - --snap-bite MM (default 0.4; PLA ~0.3; 0 = friction fit, STLs
    byte-identical to before); summary line and preview show the setting
    - verify: new snap scope (crest protrusion, groove depth, seated
    margins, remaining wall, clearance to USB relief and skirt notch,
    bite 0 repro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
    [tally-base.stl, tally-lid.stl]
2026-10-09 Fix mirrored Super Mini header columns in the perfboard drawing
    The layout drawing had the two ESP32-C3 Super Mini pin columns swapped,
    so a board wired from it put the buttons on GPIO8/GPIO9 and the OLED on
    the power pins. With the USB-C at the bottom edge and the board viewed
    from above, column 3 is 5V, GND, 3V3, GPIO4, GPIO3, GPIO2, GPIO1, GPIO0
    and column 9 is GPIO5, GPIO6, GPIO7, GPIO8, GPIO9, GPIO10, GPIO20,
    GPIO21 (mischianti photo pinout, confirmed on an assembled board).
    - render_docs.py: swap ESP_LEFT/ESP_RIGHT; wire routes follow by name
    - README: state the column contents, add a rework note for boards built
    from the earlier drawing (move each module wire to the other column,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
    [render_docs.py]
2026-10-09 Save the count to flash on every click
    A power cut right after clicking lost the last clicks: the plain build
    flushed NVS 2 s after the last change and ESPHome synced every 10 s.
    NVS is log-structured, so a 4-byte entry per click is tens of millions
    of clicks before wear matters; write immediately instead.
    - plain: putInt on every change, dirty-flag/flush machinery deleted
    - esphome: preferences flash_write_interval 1ms and update_interval 1ms
    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
2026-10-10 Plain firmware: boot blink, boot banner, stuck-button-safe boot and sleep
    Field incident: a hot-glued TP4056 and cell pressed against the solder
    side killed the display; the OLED being the only indicator made "MCU
    dead" and "display dead" look the same. Audit of the deep-sleep path
    found no firmware cause (full reset on wake, display re-initialised by
    u8g2.begin, I2C bus recovery in the driver, NVS power-loss safe), but
    one weakness: setup() spun forever on a button held LOW and the
    level-triggered wake would re-fire instantly.
    - GPIO8 blue LED lit for the length of setup(): a blink on every
    boot/wake proves the MCU runs even with a dark OLED; back to INPUT so
    it draws nothing in deep s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
    [main.cpp]
2026-10-11 Brew-method labels beside the count, OLED placement fix, 2 s save delay
    Grind chart: one header shared by both firmwares, firmware/common/grind_chart.h
    (Comandante C40 MK4 ranges from Honest Coffee Guide's table: Turkish, Espresso,
    V60, Aeropress, Pour Over, French Press, Cold Brew). Every row whose inclusive
    click range contains the count is listed to the right of the big digits, one per
    line in table order, up to four (6x10 / Roboto 10 for 1-3 lines, 5x8 / Roboto 8
    for 4). No match shows the count alone, centred; an empty table turns it off.
    Static screen, redrawn only on a click. The Makefile now mounts the repo root
    for the plain, test and ESPHome containers so ../common resolves.
    Displ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
2026-10-11 One flash write per click burst on both firmwares
    ESPHome now follows the plain build's rule instead of a fixed 2 s sync tick:
    every count change restarts a save_later script (mode: restart, delay
    ${save_delay}, global_preferences->sync()), so gaps under 2 s never write and
    the pause after the last click writes the final count once.
    flash_write_interval: never keeps the syncer component, whose shutdown hook
    still flushes before deep sleep.
    Plain: the dirty flag and timestamp move into struct SaveDelay in
    tally_logic.h (touch on a change, due after the delay) so the host test covers
    it: a burst gives one write 2 s after the last click, 1.5 s gaps give none and
    then one, it survives a millis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
2026-10-11 Case: default tact switch height 4.3 mm
    The switches in the build are 6 x 6 x 4.3 mm. With the old 5.0 default the
    caps hovered 0.7 mm above the plungers and clicked nearly flush. TACT_H 4.3
    gives cap flange 2.9 and stem 6.2 (cap 11 x 11 x 6.7), still 1 mm proud. Only
    the two cap STLs, renders.png and preview.html change; lid and base are
    byte-identical. Verify passes (105 / 70 with --snap-bite 0 / 101 with
    --omit-engraving). The docs' --tact-height examples now use 5.
2026-10-13 CI firmware builds + rolling latest release + landing-page download links (#3)
    * CI: build both firmwares, publish rolling latest release, link bins from landing page
    * Review: least-privilege CI jobs, in-place latest release update
